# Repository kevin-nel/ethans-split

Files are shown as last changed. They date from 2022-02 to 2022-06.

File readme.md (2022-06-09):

# Handwired Split Ortholinear Keyboard

keeb

- [added via/vial support](https://get.vial.today/docs/porting-to-via.html) with ``via.json``
  - [KLE can be found here](http://www.keyboard-layout-editor.com/##@@_x:1.75%3B&=0,0&=0,1&=0,2&=0,3&=0,4&=0,5&=0,6&_x:1%3B&=0,7&=0,8&=0,9&=0,10&=0,11&_w:2%3B&=0,12%3B&@_x:1.25&w:1.5%3B&=1,0&=1,1&=1,2&=1,3&=1,4&=1,5&=1,6&_x:1%3B&=1,7&=1,8&=1,9&=1,10&=1,11&=1,12&=1,13%3B&@_x:1.25&w:1.5%3B&=2,0&=2,1&=2,2&=2,3&=2,4&=2,5&=2,6&_x:1%3B&=2,7&=2,8&=2,9&=2,10&=2,11&=2,12&=2,13%3B&@_x:0.5&w:2.25%3B&=3,0&=3,1&=3,2&=3,3&=3,4&=3,5&=3,6&_x:1%3B&=3,7&=3,8&=3,9&=3,10&=3,11&=3,12&=3,13%3B&@_x:0.5&w:2.25%3B&=4,0&=4,1&=4,2&=4,3&=4,4&_h:2%3B&=4,5&=4,6&_x:1%3B&=4,7&=4,8&=4,9%3B&@_x:5.75%3B&=5,4&_x:1%3B&=5,6&_x:1%3B&=5,7&=5,8&=5,9)
- split design (I2C) left hand master
- minimal QMK (no LEDs or extra stuff)
  - [find the keycodes here](https://github.com/qmk/qmk_firmware/blob/master/docs/keycodes.md)
- compile firmware by [setting up qmk](https://docs.qmk.fm/#/newbs_getting_started) and then copying the ``./ethans-split/firmware/qmk_firmware/keyboards/ethan_split`` folder into your qmk keyboards folder and running ``qmk compile -kb ethan_split -km via``
- flash both sides using [qmk toolbox](https://github.com/qmk/qmk_toolbox/releases/tag/0.1.1)
- cols and rows are not identical for each half, consult the promicro pinout and combile the relevant firmware for each half.
pro micro pinout
  
- thanks to [this wonderful guide](https://github.com/qmk/qmk_firmware/blob/master/docs/feature_split_keyboard.md) and the excellent [qmk split keyboard docs](https://docs.qmk.fm/#/feature_split_keyboard?id=split-keyboard)

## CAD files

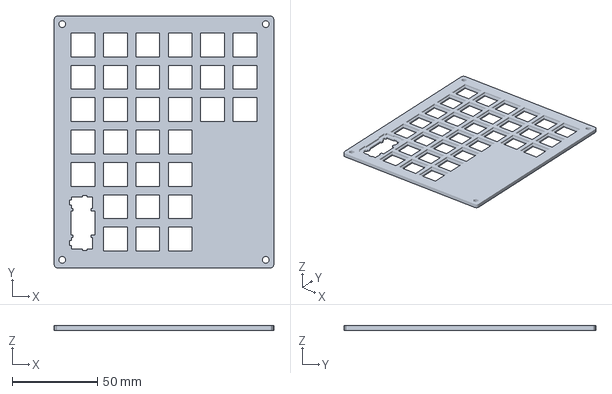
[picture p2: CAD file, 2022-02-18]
2.0/jeeboard_2-ethan-plate-R.3mf
129.0 x 148.0 x 3.00 mm

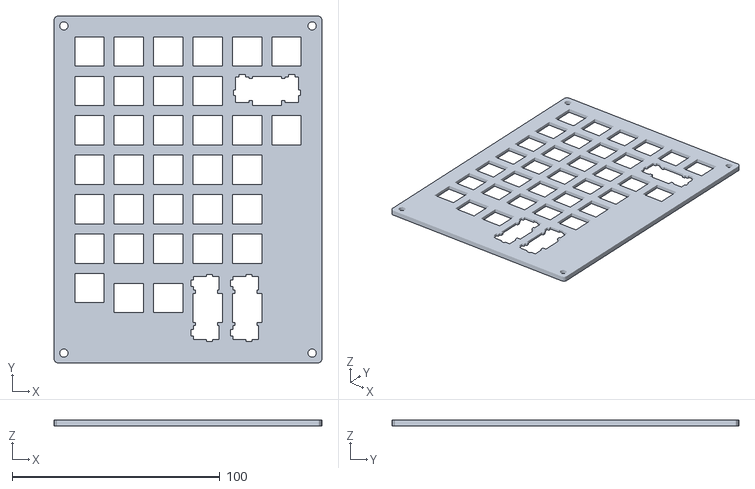
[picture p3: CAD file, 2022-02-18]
2.0/jeeboard_2-ethan-plate-L.stl
129.0 x 167.0 x 3.00

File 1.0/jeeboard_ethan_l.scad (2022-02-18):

slop = 0.0;
switch_x = 14 + slop;
switch_y = switch_x;
rounding = 2;

plate_thickness = 3;

//clip_thickness = 1.524 + slop; //mx
clip_thickness = 1.5 + slop; //gateron

outer_padding = 5;
hole_size = 4;

case_height=12;

pitch = 19;
u = pitch;

switch_positions = [
                    //row1
                    [0,-1*u,0],
                    [0,0,0],
                    [0,1*u,0],
                    [0,2*u,0],
                    [0,3*u,0],
                    [0,4*u,0],
                    [0,5*u,0],
                    //row2
                    [1*u,-1.25*u,0],
                    [1*u,0,0],
                    [1*u,1*u,0],
                    [1*u,2*u,0],
                    [1*u,3*u,0],
                    [1*u,4*u,0],
                    [1*u,5*u,0],

                    //row3
                    [2*u,-1.25*u,0],
                    [2*u,0,0],
                    [2*u,1*u,0],
                    [2*u,2*u,0],
                    [2*u,3*u,0],
                    [2*u,4*u,0],
                    [2*u,5*u,0],

                    //row4
                    [3*u,0,0],
                    [3*u,1*u,0],
                    [3*u,2*u,0],
                    [3*u,3*u,0],
                    [3*u,4*u,0],
                    [3*u,5*u,0],

                    //row5
                    [4*u,0,0],
                    [4*u,1*u,0],
                    [4*u,2*u,0],
                    [4*u,3*u,0],
                    //2u stab key rotated
                    [4*u,5*u,0],

                    //row5
                    [5*u,3*u,0],
                    //2u stab key rotated
                    [5*u,5*u,0],
                    ];

2u_stabilised_switch_positions = [
                    [3*u,-1.5*u,0],
                    [4*u,-1.5*u,0],
                    ];

module switch_hole(position){
    translate(position)
    translate([0,0,(plate_thickness-clip_thickness)/2])
    union(){
        //clip
        cube([switch_x+2, switch_y+2, plate_thickness-clip_thickness],center=true);
        //rim
        translate([0,0,plate_thickness-clip_thickness])cube([switch_x, switch_y, clip_thickness],center=true);
    }
}

module 2u_stabilised_key_hole(position){
    points = [
        [-0.50,32.2/2],
        [2.3,32.2/2],
        [2.3,30.45/2],
        [5.53,30.45/2],
        [5.53,17.15/2],
        [4.73,17.15/2],
        [4.73,14/2],
        [7,14/2],
        [7,0],

        [-7,0],
        [-7,14/2],
        [-5.97,14/2],
        [-5.97,17.15/2],
        [-6.77,17.15/2],
        [-6.77,20.80/2],
        [-7.97,20.80/2],
        [-7.97,26.80/2],
        [-6.77,26.80/2],
        [-6.77,30.45/2],
        [-0.5,30.45/2]
    ];

    translate(position)
    union(){
        //clip
        translate([0,0,plate_thickness-(clip_thickness/2)])
        linear_extrude(clip_thickness,center=true)
        union(){
            rotate([180,0,0])polygon(points);
            polygon(points);
        }

        //rim
        translate([0,0,(plate_thickness-clip_thickness)/2])
        linear_extrude(plate_thickness-clip_thickness,center=true)
        union(){
            rotate([180,0,0])offset(delta=1){polygon(points);}
            offset(delta=1){polygon(points);}
        }
    }

}

module plate_gen(){
    points = [
        [-.5*u,-2.5*u,0],
        [-.5*u,5.5*u,0],
        [5.5*u,5.5*u,0],
        [5.5*u,-2.5*u,0],
        ];
    hull(){
    for(i=points){
        translate(i)cylinder(r1=rounding, r2=rounding, h=plate_thickness);
    }
    }
}
difference(){
    //plate
    plate_gen();
    // cutouts for switches and stabs
    union(){
        //stabs from position list
        for(i=2u_stabilised_switch_positions){
            2u_stabilised_key_hole(i);
        }
        //custom positioned (rotated) stabs
        translate([.5*u,7.5*u,0])rotate([180,180,90])
        2u_stabilised_key_hole([3.5*u,4*u,0]);

        for(i=switch_positions){
            switch_hole(i);
        }
    }
}

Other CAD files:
1.0/jeeboard_ethan_r.scad
2.0/jeeboard_2-ethan-plate-L.scad
2.0/jeeboard_2-ethan-plate-R.scad
2.0/jeeboard_2-ethan-plate-R.stl
2.0/jeeboard_2.scad

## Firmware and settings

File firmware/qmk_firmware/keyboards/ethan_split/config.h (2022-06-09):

/*
Copyright 2012 Jun Wako <wakojun@gmail.com>
Copyright 2015 Jack Humbert

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
You should have received a copy of the GNU General Public License
along with this program.  If not, see <http://www.gnu.org/licenses/>.
*/

#pragma once

#include "config_common.h"

#define MATRIX_ROWS 12
#define MATRIX_COLS 7

/*
#define MATRIX_COL_PINS {B6, B2, B3, B1, F7, F6, F5} //left
#define MATRIX_ROW_PINS_RIGHT {C6, D7, E6, B4, B5} //right
#define MATRIX_ROW_PINS {D4, C6, D7, E6, B4, B5} //left
*/

#define MATRIX_COL_PINS {F5, F6, F7, B1, B3, B2, B6} //both
#define MATRIX_ROW_PINS_RIGHT {B5, B4, E6, D7, C6, D4} //right
#define MATRIX_ROW_PINS {B5, B4, E6, D7, C6, D4} //left


#define DIODE_DIRECTION COL2ROW
#define DEBOUNCE 5

#define USE_I2C

#define SPLIT_USB_DETECT
#define SPLIT_USB_TIMEOUT 2000
#define SPLIT_USB_TIMEOUT_POLL 10

#define MASTER_LEFT


// stuff to get VIA support

#define VENDOR_ID 0x7063 //"PC" plainoldcheese
#define PRODUCT_ID 0x0002
#define DEVICE_VER 0x0001
#define MANUFACTURER plainoldcheese
#define PRODUCT battleship
#define DESCRIPTION custom split keyboard

#define DYNAMIC_KEYMAP_LAYER_COUNT 4

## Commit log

2022-02-18 upload files
    this code has not been compiled or tested, it is just preliminary until the board has been wired up and I am able to test
    [jeeboard_2-ethan-plate-L.scad, jeeboard_2-ethan-plate-L.stl, jeeboard_2-ethan-plate-R.3mf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]
2022-06-09 SQUASH BUGS
    firmware was not right and via.json had an incorrect kle.json under the keymap
    [config.h]

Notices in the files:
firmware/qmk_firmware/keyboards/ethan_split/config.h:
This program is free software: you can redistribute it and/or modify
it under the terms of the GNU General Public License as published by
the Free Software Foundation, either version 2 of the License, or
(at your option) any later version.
